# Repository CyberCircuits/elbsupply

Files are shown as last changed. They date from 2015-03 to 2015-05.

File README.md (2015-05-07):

## ElbSupply - A simple linear bench supply

ElbSupply is a linear bench power supply with an output voltage range of 0-20V and output current range of 0-3A.

Here are the OSHpark renderings of the boards:

For project details visit the [project page on Hackaday.io](https://hackaday.io/project/4407-elbsupply-simple-linear-bench-supply)

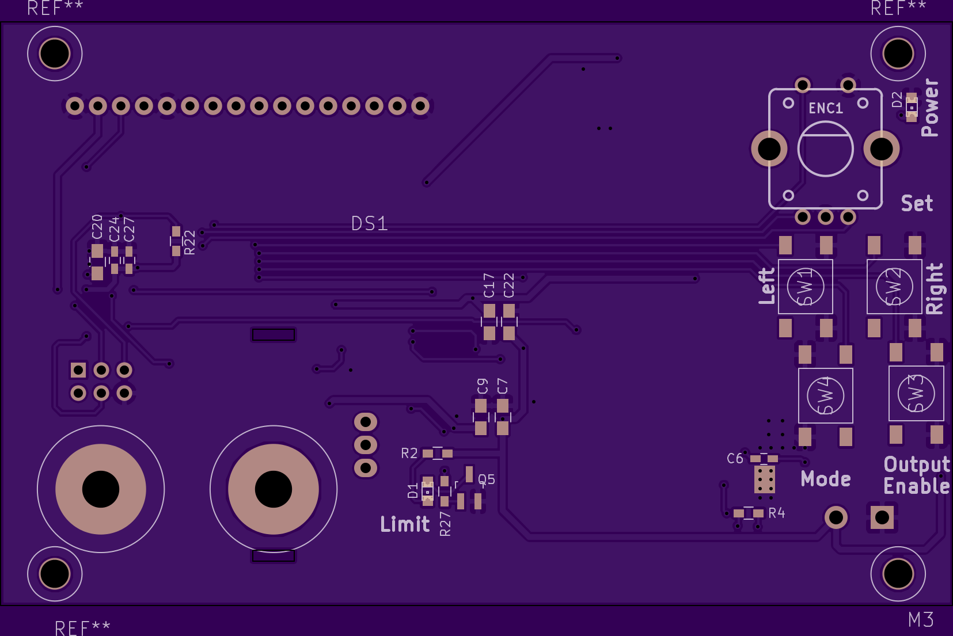
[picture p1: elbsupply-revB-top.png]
"Rev. B board top" Rev. B board top
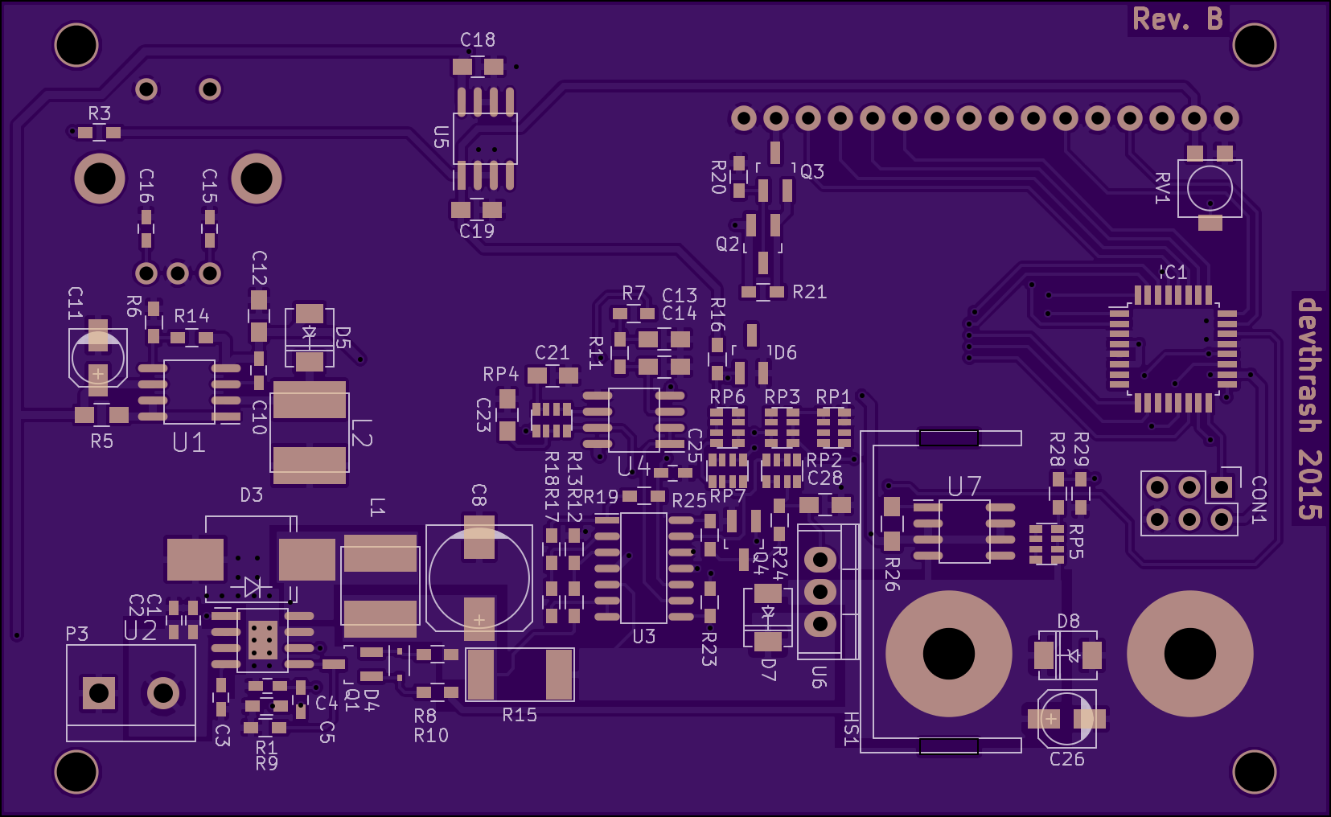
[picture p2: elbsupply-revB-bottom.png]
"Rev. B board bottom" Rev. B board bottom


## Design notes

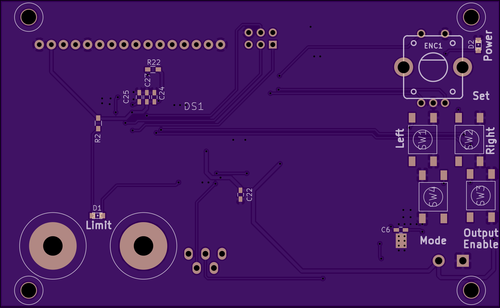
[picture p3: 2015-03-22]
elbsupply-revA-top.png

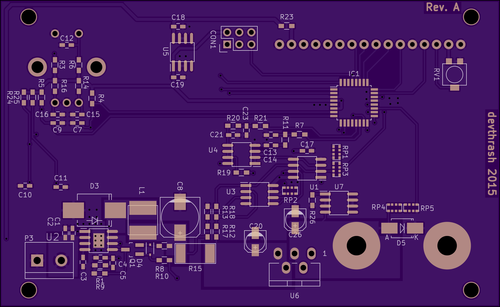
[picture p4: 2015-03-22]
elbsupply-revA-bottom.png

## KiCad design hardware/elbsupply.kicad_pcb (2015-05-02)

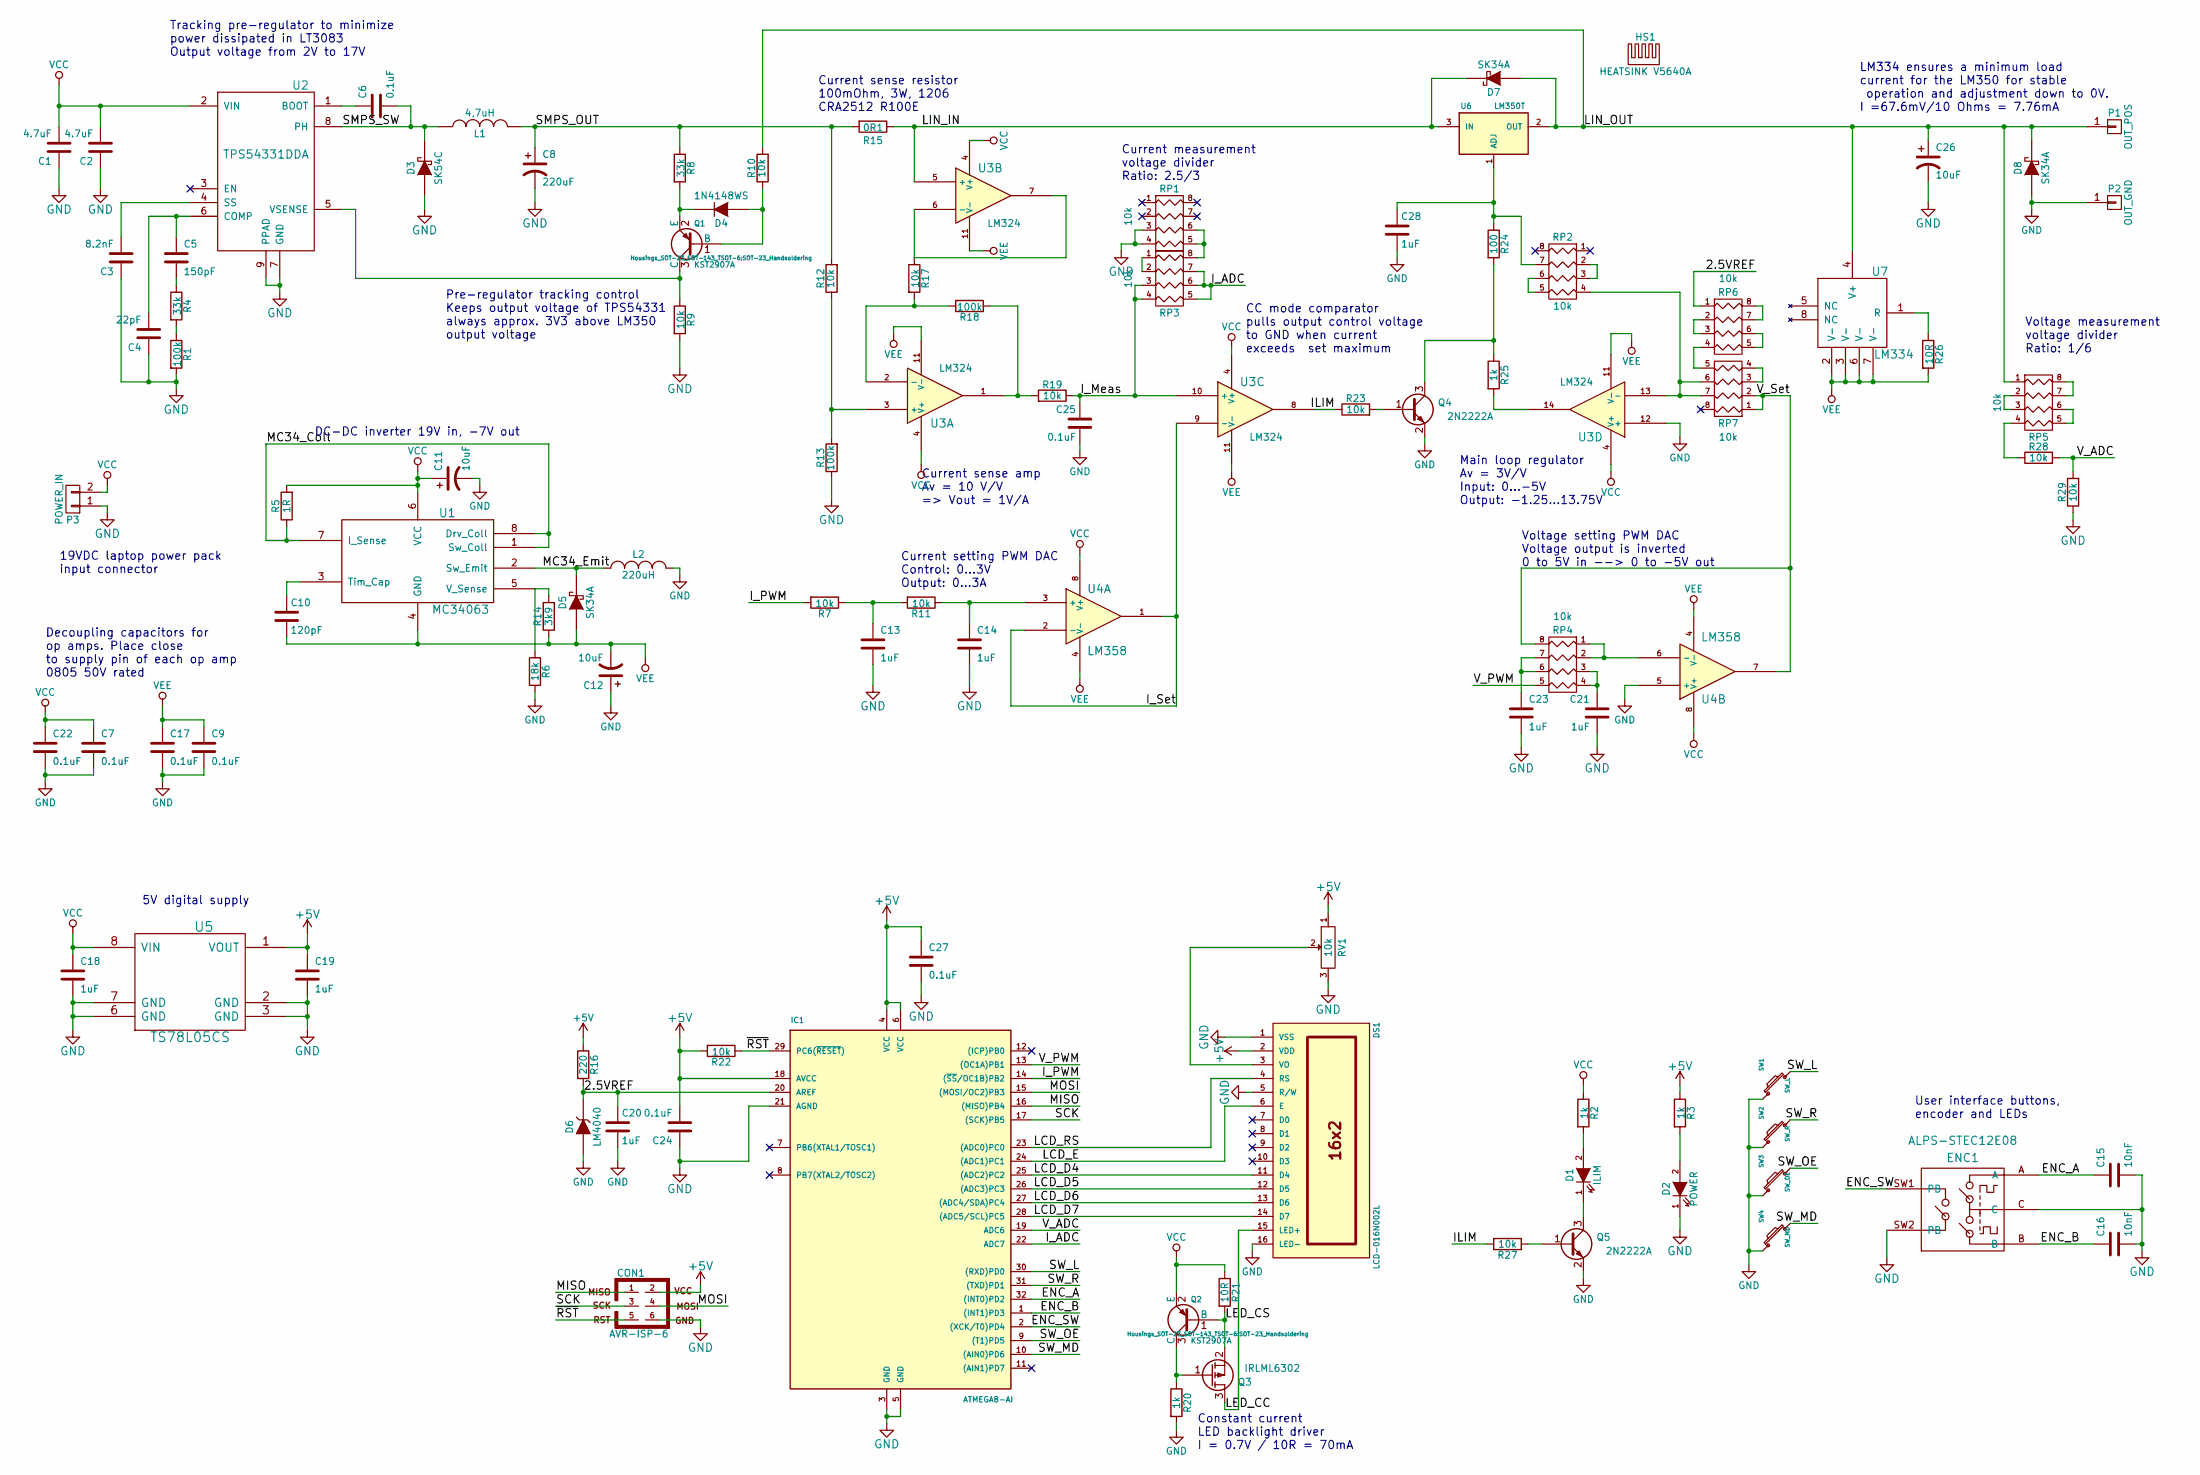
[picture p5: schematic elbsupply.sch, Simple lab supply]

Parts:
C1, C2: 4.7uF; C_0805_HandSoldering
C3: 8.2nF; C_0603_HandSoldering
C4: 22pF; C_0603_HandSoldering
C5: 150pF; C_0603_HandSoldering
C6, C7, C9, C17, C22, C24, C25, C27: 0.1uF; C_0805_HandSoldering
C8: 220uF; c_elec_8x10.5
C10: 120pF; C_0603_HandSoldering
C11, C26: 10uF; c_elec_4x4.5
C12: 10uF; C_0805_HandSoldering
C13, C14, C18, C19, C20, C21, C23, C28: 1uF; C_0805_HandSoldering
C15, C16: 10nF; C_0603_HandSoldering
CON1: AVR-ISP-6; Pin_Header_Straight_2x03
D1: ILIM; LED-0805
D2: POWER; LED-0805
D3: SK54C; Diode-SMC_Handsoldering
D4: 1N4148WS; SOD-323
D5, D7, D8: SK34A; DO-214-AC_SMA
D6: LM4040; SOT-23_Handsoldering
DS1: LCD-016N002L; LCD16X2
ENC1: ALPS-STEC12E08
HS1: HEATSINK V5640A; Heatsink-V5640A
IC1: ATMEGA8-AI; TQFP-32_7x7mm_Pitch0.8mm
L1: 4,7uH; 242418FPS-Fastron
L2: 220uH; 242418FPS-Fastron
P1: OUT_POS; SKS-PK10A
P2: OUT_GND; SKS-PK10A
P3: POWER_IN; bornier2
Q1, Q2: KST2907A; SOT-23_Handsoldering
Q3: IRLML6302; SOT-23_Handsoldering
Q4, Q5: 2N2222A; SOT-23_Handsoldering
R1, R13, R18: 100k; R_0603_HandSoldering
R2, R3, R20, R25: 1k; R_0603_HandSoldering
R4, R8: 33k; R_0603_HandSoldering
R5: 1R; R_0805_HandSoldering
R6: 18k; R_0603_HandSoldering
R7, R9, R10, R11, R12, R17, R19, R22, R23, R27, R28, R29: 10k; R_0603_HandSoldering
R14: 3k9; R_0603_HandSoldering
R15: 0R1; CRA2512-Bourns
R16: 220; R_0603_HandSoldering
R21: 10R; R_0603_HandSoldering
R24: 100; R_0603_HandSoldering
R26: 10R; R_0805_HandSoldering
RP1, RP2, RP3, RP4, RP5, RP6, RP7: 10k; YC164-Yageo-Handsoldering
RV1: 10k; BITech-23B
SW1: SW_L; Button-SMT-standard
SW2: SW_R; Button-SMT-standard
SW3: SW_OE; Button-SMT-standard
SW4: SW_MD; Button-SMT-standard
U1: MC34063; SO8
U2: TPS54331DDA; SO8-PowerPAD
U3: LM324; SO14
U4: LM358; SO8
U5: TS78L05CS; SO8
U6: LM350T; TO-220
U7: LM334; SO8

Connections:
+5V: C19.1, C24.2, C27.1, CON1.2, DS1.2 (VDD), IC1.4 (VCC), IC1.6 (VCC), IC1.18 (AVCC), R3.1, R16.1, R22.2, RV1.1, U5.1 (VOUT)
/2.5VREF: C20.1, D6.1 (K), IC1.20 (AREF), R16.2, RP6.1
/ENC_A: C15.1, ENC1.A, IC1.32 ((INT0)PD2)
/ENC_B: C16.1, ENC1.B, IC1.1 ((INT1)PD3)
/ENC_SW: ENC1.SW1 (PB), IC1.2 ((XCK/T0)PD4)
/ILIM: R23.1, R27.2, U3.8
/I_ADC: IC1.22 (ADC7), RP3.5 (R4), RP3.6 (R3), RP3.7 (R2)
/I_Meas: C25.1, R19.1, RP3.3, RP3.4, U3.10 (+)
/I_PWM: IC1.14 ((~SS~/OC1B)PB2), R7.2
/I_Set: U3.9 (-), U4.1, U4.2 (-)
/LCD_D4: DS1.11 (D4), IC1.25 ((ADC2)PC2)
/LCD_D5: DS1.12 (D5), IC1.26 ((ADC3)PC3)
/LCD_D6: DS1.13 (D6), IC1.27 ((ADC4/SDA)PC4)
/LCD_D7: DS1.14 (D7), IC1.28 ((ADC5/SCL)PC5)
/LCD_E: DS1.6 (E), IC1.24 ((ADC1)PC1)
/LCD_RS: DS1.4 (RS), IC1.23 ((ADC0)PC0)
/LED_CC: DS1.15 (LED+), Q3.3 (D)
/LED_CS: Q2.1 (B), Q3.2 (S), R21.2
/LIN_IN: D7.2 (K), R15.1, U3.5 (+), U6.3 (IN)
/LIN_OUT: C26.1, D7.1 (A), D8.2 (K), P1.1, R10.2, RP5.1, U6.2 (OUT), U7.4 (V+)
/MC34_Coll: R5.1, U1.1 (Sw_Coll), U1.7 (I_Sense), U1.8 (Drv_Coll)
/MC34_Emit: D5.2 (K), L2.1, U1.2 (Sw_Emit)
/MISO: CON1.1, IC1.16 ((MISO)PB4)
/MOSI: CON1.4, IC1.15 ((MOSI/OC2)PB3)
/SCK: CON1.3, IC1.17 ((SCK)PB5)
/SMPS_OUT: C8.1, L1.2, R8.1, R12.2, R15.2
/SMPS_SW: C6.2, D3.2 (K), L1.1, U2.8 (PH)
/SW_L: IC1.30 ((RXD)PD0), SW1.2
/SW_MD: IC1.10 ((AIN0)PD6), SW4.2
/SW_OE: IC1.9 ((T1)PD5), SW3.2
/SW_R: IC1.31 ((TXD)PD1), SW2.2
/V_ADC: IC1.19 (ADC6), R28.2, R29.2
/V_PWM: IC1.13 ((OC1A)PB1), RP4.5 (R4)
/V_Set: RP4.8 (R1), RP7.1, RP7.2, U4.7
/~RST~: CON1.5, IC1.29 (PC6(~RESET~)), R22.1
GND: C1.1, C2.1, C3.1, C4.1, C7.2, C8.2, C9.2, C11.2, C12.1, C13.2, C14.2, C15.2, C16.2, C17.2, C18.2, C19.2, C20.2, C21.2, C22.2, C23.2, C24.1, C25.2, C26.2, C27.2, C28.2, CON1.6, D2.1 (K), D3.1 (A), D6.2 (A), D8.1 (A), DS1.1 (VSS), DS1.5 (R/W), DS1.16 (LED-), ENC1.C, ENC1.SW2 (PB), IC1.3 (GND), IC1.5 (GND), IC1.21 (AGND), L2.2, P2.1, P3.1, Q4.2 (E), Q5.2 (E), R1.2, R6.2, R9.2, R13.1, R20.2, R29.1, RP1.3, RP1.4, RV1.3, SW1.1, SW2.1, SW3.1, SW4.1, U2.7 (GND), U2.9 (PPAD), U3.12 (+), U4.5 (+), U5.2 (GND), U5.3 (GND), U5.6 (GND), U5.7 (GND)
unnamed: C3.2, U2.4 (SS)
unnamed: C4.2, C5.1, U2.6 (COMP)
unnamed: C5.2, R4.1
unnamed: C6.1, U2.1 (BOOT)
unnamed: C10.1, U1.3 (Tim_Cap)
unnamed: C13.1, R7.1, R11.2
unnamed: C14.1, R11.1, U4.3 (+)
unnamed: C21.1, RP4.3, RP4.4
unnamed: C23.1, RP4.6 (R3), RP4.7 (R2)
unnamed: C28.1, R24.1, RP2.7 (R2), U6.1 (ADJ)
unnamed: D1.1 (K), Q5.3 (C)
unnamed: D1.2 (A), R2.2
unnamed: D2.2 (A), R3.2
unnamed: D4.1 (A), Q1.1 (B), R10.1
unnamed: D4.2 (K), Q1.2 (E), R8.2
unnamed: DS1.3 (VO), RV1.2
unnamed: Q1.3 (C), R9.1, U2.5 (VSENSE)
unnamed: Q2.3 (C), Q3.1 (G), R20.1
unnamed: Q4.1 (B), R23.2
unnamed: Q4.3 (C), R24.2, R25.1
unnamed: Q5.1 (B), R27.1
unnamed: R1.1, R4.2
unnamed: R12.1, R13.2, U3.3 (+)
unnamed: R6.1, R14.2, U1.5 (V_Sense)
unnamed: R17.1, U3.6 (-), U3.7
unnamed: R17.2, R18.2, U3.2 (-)
unnamed: R18.1, R19.2, U3.1
unnamed: R25.2, U3.14
unnamed: R26.1, U7.1 (R)
unnamed: R28.1, RP5.4
unnamed: RP1.5 (R4), RP1.6 (R3), RP3.8 (R1)
unnamed: RP2.2, RP2.3
unnamed: RP2.4, RP7.6 (R3), RP7.7 (R2), U3.13 (-)
unnamed: RP2.5 (R4), RP2.6 (R3)
unnamed: RP3.1, RP3.2
unnamed: RP4.1, RP4.2, U4.6 (-)
unnamed: RP5.2, RP5.3
unnamed: RP5.5 (R4), RP5.6 (R3)
unnamed: RP5.7 (R2), RP5.8 (R1)
unnamed: RP6.2, RP6.3
unnamed: RP6.4, RP7.5 (R4)
unnamed: RP6.5 (R4), RP6.6 (R3)
unnamed: RP6.7 (R2), RP6.8 (R1)
unnamed: RP7.3, RP7.4
VCC: C1.2, C2.2, C7.1, C11.1, C18.1, C22.1, P3.2, Q2.2 (E), R2.1, R5.2, R21.1, U1.6 (VCC), U2.2 (VIN), U3.4 (V+), U4.8 (V+), U5.8 (VIN)
VEE: C9.1, C10.2, C12.2, C17.1, D5.1 (A), R14.1, R26.2, U1.4 (GND), U3.11 (V-), U4.4 (V-), U7.2 (V-), U7.3 (V-), U7.6 (V-), U7.7 (V-)

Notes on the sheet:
Current sense amp Av = 10 V/V => Vout = 1V/A
Main loop regulator Av = 3V/V Input: 0...-5V Output: -1.25...13.75V
Current setting PWM DAC Control: 0...3V Output: 0...3A
Voltage setting PWM DAC Voltage output is inverted 0 to 5V in --> 0 to -5V out
Pre-regulator tracking control Keeps output voltage of TPS54331 always approx. 3V3 above LM350 output voltage
Tracking pre-regulator to minimize power dissipated in LT3083 Output voltage from 2V to 17V
CC mode comparator pulls output control voltage to GND when current exceeds set maximum
Current measurement voltage divider Ratio: 2.5/3
5V digital supply
Current sense resistor 100mOhm, 3W, 1206 CRA2512 R100E
Constant current LED backlight driver I = 0.7V / 10R = 70mA
Decoupling capacitors for op amps. Place close to supply pin of each op amp 0805 50V rated
19VDC laptop power pack input connector
DC-DC inverter 19V in, -7V out
User interface buttons, encoder and LEDs
LM334 ensures a minimum load current for the LM350 for stable operation and adjustment down to 0V. I =67.6mV/10 Ohms = 7.76mA
Voltage measurement voltage divider Ratio: 1/6

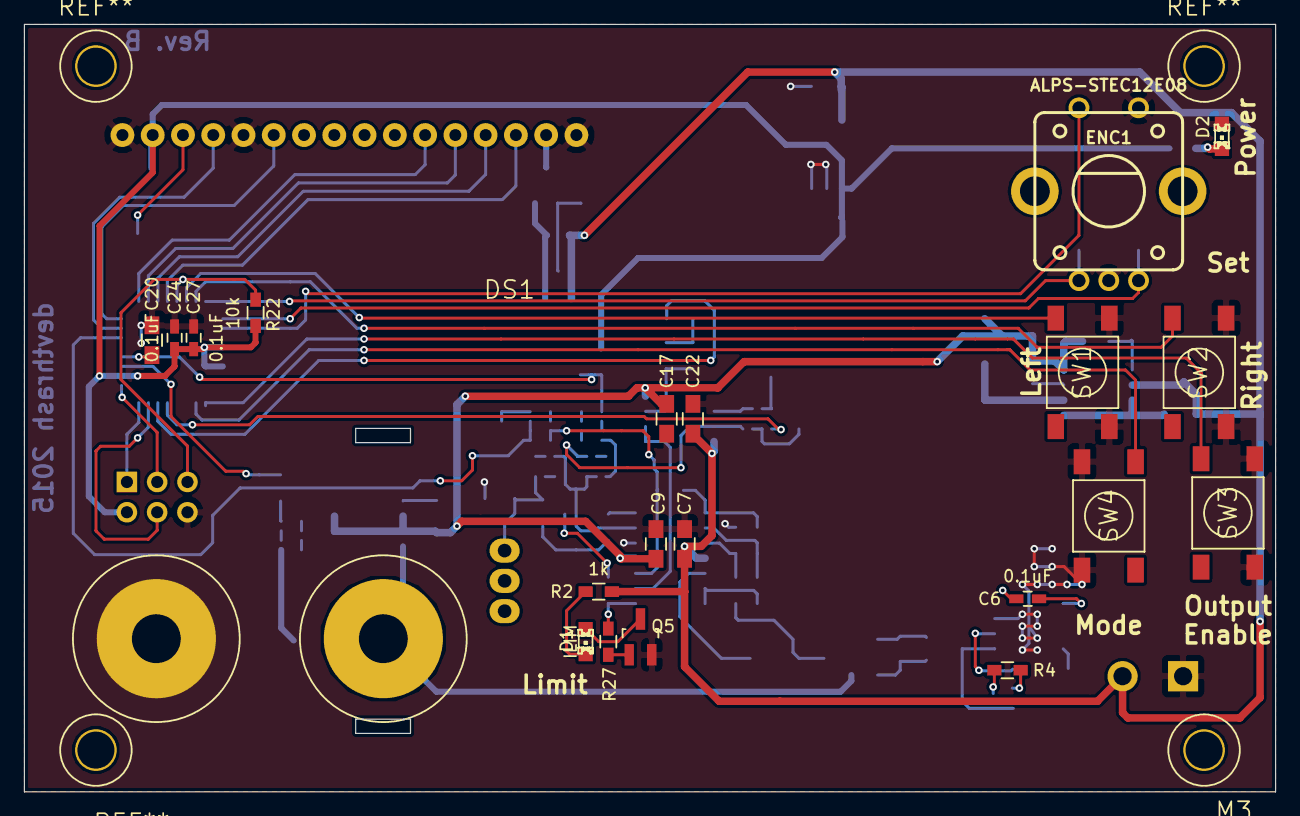
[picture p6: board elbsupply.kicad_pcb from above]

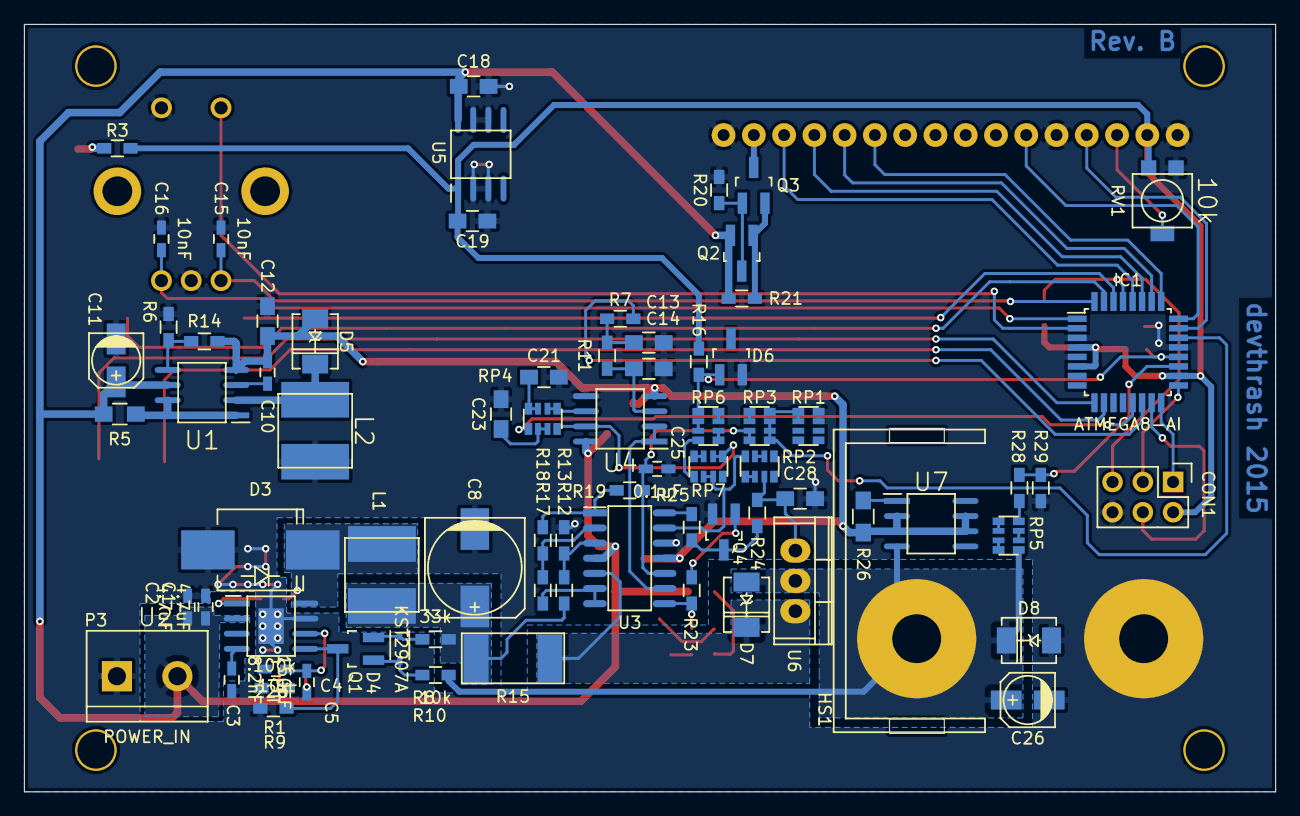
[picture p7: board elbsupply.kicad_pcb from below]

Board: 2 copper layers, 105.0 x 64.4 mm, 100 parts (76 on the bottom side), 82 nets.

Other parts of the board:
M3: Screw_PAN_Head_M3

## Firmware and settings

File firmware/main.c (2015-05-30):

#define F_CPU 8000000UL
#include <avr/io.h>
#include <avr/interrupt.h>
#include <util/delay.h>

#include "lcd.h"
#include "adc.h"
#include "pwm.h"

/* I/O mapping on the PCB
 * 
 * Inputs:
 * Button Left: 			PD0
 * Button right: 			PD1
 * Encoder button: 			PD2
 * Encoder A:				PD3
 * Encoder B:				PD4				
 * Button output enable: 	PD5
 * Button mode: 			PD6
 * 
 * output voltage:			ADC6
 * output current:			ADC7
 * 
 * Outputs:
 * Voltage set PWM:			PB1
 * Current set PWM:			PB2
 * LCD_RS:					PC0
 * LCD_E:					PC1
 * LCD_D4:					PC2
 * LCD_D5:					PC3
 * LCD_D6:					PC4
 * LCD_D7:					PC5
 */
#define BTN_LEFT	0x01
#define BTN_RIGHT	0x02
#define ENC_BTN		0x04
#define ENC_A		0x08
#define ENC_B		0x10
#define BTN_OE 		0x20
#define BTN_MODE	0x40

// define some flags for easier readability 
#define OUTMODE_CV 	0 
#define OUTMODE_CC 	1

// cursor shift directions
#define CURSHIFT_LEFT 0
#define CURSHIFT_RIGHT 1

// variables for LCD
char displayBuffer[2][16] = {
	"00.00V 0000mA CV",
	"00.00V 0000mA   "
};

uint8_t displayCurpos = 0;	// cursor position inside the display buffer
volatile uint16_t adcResampleTimeout = 0;

// voltage/current set points and actual measurements
// Adc = measured values
// Set = set values input by the user
// SetBuf = internal set buffer used for updating the PWM
uint16_t voltageSet, voltageSetBuf, voltageAdc = 0;
uint16_t currentSet, currentSetBuf, currentAdc = 0;

// PSU output mode and status
// 0 = output disabled, 1 = output enabled
uint8_t psuOutEnabled = 0;		
// 0 = constant voltage, 1 = constant current
uint8_t psuOutMode = 0;			

/* This approach to switch debouncing has been borrowed from Jack Ganssle
 * See http://www.ganssle.com/debouncing-pt2.htm for detailed description
 */
// number of timer interrupts after which a switch is considered debounced
#define SW_CHECKS 30
uint8_t swDebouncedState; 						// debounced state of the switches
volatile uint8_t swStateBuf[SW_CHECKS] = {0}; 	// holds SW_CHECKS consecutive switch state readings
volatile uint8_t swStateIndex = 0;				// array index for number of checks performed

/* Reads the raw state of the port input registers and fuses them
 * together into one byte to be used in the debouncing routine
 * 
 * The byte layout is as follows:
 * Bit	6		5		 4		  3		    2 		1 			0
 * BTN_MODE | BTN_OE | ENC_B | ENC_A | ENC_BTN | BTN_RIGHT | BTN_LEFT
 */
uint8_t getSwitchRaw(void)
{
	uint8_t tmp;
	tmp = (PIND & 0x7F) ^ 0xFF;	// invert read values because switches are active low
	return tmp;
}

/* Returns debounced state of the switches 
 * Return bit values: 1 if switch has changed, 0 otherwise 
 */
uint8_t getSwitchDebounced(void)
{
	uint8_t i,j,tmp;
	j = 0xFF;
	for (i = 0; i < SW_CHECKS; i++) j = j & swStateBuf[i];
	tmp = swDebouncedState ^ j;
	swDebouncedState = j;
	return tmp;
}

/* variables for encoder decoding
 * Encoder outputs are connected to external interrupt pins on 
 * the AVR which generate interrupts on any level change.
 *
 * In the ISR patterns are generated which are compared to the
 * reference patterns in order to determine which way the encoder
 * was spun
 */
uint8_t encRefLeft[5] = {0, 2, 3, 1, 0};
uint8_t encRefRight[5] = {0, 1, 3, 2, 0};
volatile uint8_t encTurnBuf[5];
volatile uint8_t encTurnIndex = 0;

int8_t getEncoderTurn(void)
{
	uint8_t i,j;
	// check wether the pattern matches with being turned right
	j = 5;
	for (i = 0; i < 5; i++)
	{
		if (encTurnBuf[i] == encRefRight[i]) j--;
	}
	
	if (j == 0) return 1;
	// check wether the pattern matches with being turend left
	j = 5;
	for (i = 0; i < 5; i++)
	{
		if (encTurnBuf[i] == encRefLeft[i]) j--;
	}
	
	if (j == 0) return -1;
	
	return 0;
}

/* shifts the cursor display position left or right depending on inc
 * if inc = 1: shift right
 * if inc = 0: shift left
 * this function ensures that the cursor is only moved to a position
 * of one of the digits of the set points on the LCD (cursor doesn't
 * move to digits that can't be modified)
 */
void lcdShiftCursor(uint8_t inc)
{
	switch (displayCurpos)
	{
	case 0:
		if (inc) displayCurpos++; 
		break;
		
	case 1:
		if (inc) displayCurpos += 2; 
		else displayCurpos--;
		break;
		
	case 3:
		if (inc) displayCurpos++;
		else displayCurpos -= 2;
		break;
		
	case 4: 
		if (inc) displayCurpos += 3;
		else displayCurpos--;
		break;
	
	case 7:
		if (inc) displayCurpos++;
		else displayCurpos -= 3;
		break;
	
	case 8:
		if (inc) displayCurpos++;
		else displayCurpos--;
		break;
				
	case 9:
		if (inc) displayCurpos++;
		else displayCurpos--;
		break;
						
	case 10:
		if (!inc) displayCurpos--;
		break;
	}
}

// define possible states of the finite state machine
typedef enum{
	STATE_IDLE,
	STATE_CRIGHT,
	STATE_CLEFT,
	STATE_ENCINC,
	STATE_ENCDEC,
	STATE_OE,
	STATE_MODE,
	STATE_PWMUPDATE,
	STATE_LCDUPDATE
}
SM_STATE;

// finite state machine registers
SM_STATE stateNext;

// each state of the FSM has it's own function
// return value is the next state of the FSM
SM_STATE stateIdle(void)
{
	uint8_t tmp;
	int8_t encState;
	
	tmp = getSwitchDebounced();
	encState = getEncoderTurn();
	
	if ( (swDebouncedState & BTN_OE) && (tmp & BTN_OE) ) {
		return STATE_OE;
	} else if ( (swDebouncedState & BTN_MODE) && (tmp & BTN_MODE)) {
		return STATE_MODE;
	} else if ( (swDebouncedState & BTN_LEFT) && (tmp & BTN_LEFT) ) {
		return STATE_CLEFT;
	} else if ( (swDebouncedState & BTN_RIGHT) && (tmp & BTN_RIGHT) ) {
		return STATE_CRIGHT;
	} else if ( encState == 1 ) {
		return STATE_ENCINC;
	} else if ( encState == -1 ) {
		return STATE_ENCDEC;
	} else if (adcResampleTimeout >= 244) {
		adcResampleTimeout = 0;
		return STATE_LCDUPDATE;
	} else {
		return STATE_IDLE;
	}
}

SM_STATE stateCRight(void)
{
	// shift the display cursor right by one
	lcdShiftCursor(CURSHIFT_RIGHT);
	LCD_setpos(displayCurpos);
	return STATE_IDLE;
}

SM_STATE stateCLeft(void)
{
	// shift the display cursor left by one
	lcdShiftCursor(CURSHIFT_LEFT);
	LCD_setpos(displayCurpos);
	return STATE_IDLE;
}

SM_STATE stateEncInc(void)
{
	// increase output voltage or current depending on cursor position
	switch (displayCurpos){
	case 0:
		if (voltageSet < 501) voltageSet += 1000;
		break;
					
	case 1:
		if (voltageSet < 1401) voltageSet += 100;
		break;
						
	case 3:
		if (voltageSet < 1491) voltageSet += 10;
		break;
						
	case 4:
		if (voltageSet < 1500) voltageSet += 1;
		break;
						
	case 7:
		if (currentSet < 2001) currentSet += 1000;
		break;
						
	case 8:
		if (currentSet < 2901) currentSet += 100;
		break;
						
	case 9:
		if (currentSet < 2991) currentSet += 10;
		break;
						
	case 10:
		if (currentSet < 2999) currentSet += 1;
		break;
	}
				
	// check wether the output is enabled
	if (psuOutEnabled == 1){
		// update internal set point buffers
		voltageSetBuf = voltageSet;
		currentSetBuf = currentSet;
		// update PWM
		return STATE_PWMUPDATE;
	} else {
		return STATE_LCDUPDATE;
	}
}

SM_STATE stateEncDec(void)
{
	// reduce output voltage or current depending on cursor position
	switch (displayCurpos){
	case 0: 
		if (voltageSet > 999) voltageSet -= 1000;
		break;
					
	case 1:
		if (voltageSet > 99) voltageSet -= 100;
		break;
						
	case 3:
		if (voltageSet > 9) voltageSet -= 10;
		break;
						
	case 4:
		if (voltageSet > 0) voltageSet -= 1;
		break;
						
	case 7:
		if (currentSet > 999) currentSet -= 1000;
		break;
						
	case 8:
		if (currentSet > 99) currentSet -= 100;
		break;
						
	case 9:
		if (currentSet > 9) currentSet -= 10;
		break;
					
	case 10:
		if (currentSet > 0) currentSet -= 1;
		break;
	}
	
	// check wether the output is enabled
	if (psuOutEnabled == 1){
		// update internal set point buffers
		voltageSetBuf = voltageSet;
		currentSetBuf = currentSet;
		// update PWM
		return STATE_PWMUPDATE;
	} else {
		return STATE_LCDUPDATE;
	}	
}

SM_STATE stateOE(void)
{
	// toggle output enable status bit
	psuOutEnabled ^= 1; 
					
	// enable output	
	if (psuOutEnabled == 1){
		// constant current mode
		if (psuOutMode == OUTMODE_CC){
			voltageSetBuf = 1500;
		} else { 						// constant voltage with current limiting mode
			voltageSetBuf = voltageSet;
		}
					
		currentSetBuf = currentSet;
	} else { 							// disable output
		voltageSetBuf = 0;
		currentSetBuf = 0;
	}
	
	return STATE_PWMUPDATE;
}

SM_STATE stateMode(void)
{
	// toggle internal output mode flag and disable output
	psuOutMode ^= 1;
	return STATE_OE;
}

SM_STATE statePWMUpdate(void)
{
	PWM_setPSUOutV(voltageSetBuf);
	PWM_setPSUOutI(currentSetBuf);
	return STATE_LCDUPDATE;
}

SM_STATE stateLCDUpdate(void)
{
	// measure actual output voltage and current
	voltageAdc = ADC_readPSUOutV();
	currentAdc = ADC_readPSUOutI();
	
	// format output voltage reading 
	displayBuffer[1][0] = (voltageAdc / 1000) + 48;
	displayBuffer[1][1] = ((voltageAdc % 1000) / 100) + 48;
	displayBuffer[1][3] = ((voltageAdc % 100) / 10) + 48;
	displayBuffer[1][4] = (voltageAdc % 10) + 48;
				
	// format output current reading
	displayBuffer[1][7] = (currentAdc / 1000) + 48;
	displayBuffer[1][8] = ((currentAdc % 1000) / 100) + 48;
	displayBuffer[1][9] = ((currentAdc % 100) / 10) + 48;
	displayBuffer[1][10] = (currentAdc % 10) + 48;
				
	// format output voltage setting
	displayBuffer[0][0] = (voltageSet / 1000) + 48;
	displayBuffer[0][1] = ((voltageSet % 1000) / 100) + 48;
	displayBuffer[0][3] = ((voltageSet % 100) / 10) + 48;
	displayBuffer[0][4] = (voltageSet % 10) + 48;
				
	// format output current setting
	displayBuffer[0][7] = (currentSet / 1000) + 48;
	displayBuffer[0][8] = ((currentSet % 1000) / 100) + 48;
	displayBuffer[0][9] = ((currentSet % 100) / 10) + 48;
	displayBuffer[0][10] = (currentSet % 10) + 48;
	
	// display "OE" marker if output is enabled
	if (psuOutEnabled == 1){
		displayBuffer[1][14] = 'O';
		displayBuffer[1][15] = 'E';
	} else {
		displayBuffer[1][14] = ' ';
		displayBuffer[1][15] = ' ';
	}
				
	// indicate wether PSU is in CC or CV mode
	if (psuOutMode == OUTMODE_CC)
	{
		displayBuffer[0][15] = 'C';
	} else {
		displayBuffer[0][15] = 'V';
	}
	
	cli();		
	// push updated displayBuffer to LCD
	LCD_set_cursor(0, 0);
	LCD_puts(displayBuffer[0]);
	LCD_set_cursor(1, 0);
	LCD_puts(displayBuffer[1]);
	LCD_setpos(displayCurpos);
	sei();
	
	return STATE_IDLE;
}

int main(void)
{
	// low level initialization
	LCD_init(0x28, 0x0E);	
	ADC_init();
	PWM_init();
	
	// input switches
	DDRB &= ~0xC0;
	DDRD &= ~0x7F;
		
	// enable pull up resistors
	PORTD |= 0x7F;

	voltageSet = 500;
	currentSet = 3000;
	
	// initialize FSM registers
	stateNext = STATE_LCDUPDATE;

	// configure external interrupts for encoder
	// any logical change in the INT0/1 pins causes interrupt
	MCUCR |= (1<<ISC10) | (1<<ISC00);
	GICR |= (1<<INT1) | (1<<INT0);

	// set up SysTick timer
	// Timer 0
	TIMSK |= (1<<TOIE0);	// enable overflow interrupt
	TCCR0 |= (1<<CS01) | (1<<CS00); // prescaler 64, interrupt freq: 8MHz/(256*64) = 488Hz
	sei();
	
	// simply execute the FSM
	while (1){
		
		switch (stateNext){
		case STATE_IDLE:
			stateNext = stateIdle();
			break;
				
		case STATE_CRIGHT:
			stateNext = stateCRight();
			break;
				
		case STATE_CLEFT:
			stateNext = stateCLeft();
			break;
				
		case STATE_ENCINC:
			stateNext = stateEncInc();
			break;
				
		case STATE_ENCDEC:
			stateNext = stateEncDec();
			break;
				
		case STATE_OE:
			stateNext = stateOE();
			break;
				
		case STATE_MODE:
			stateNext = stateMode();	
			break;
				
		case STATE_PWMUPDATE:
			stateNext = statePWMUpdate();
			break;
				
		case STATE_LCDUPDATE:
			stateNext = stateLCDUpdate();
			break;
		}
		
	}
}

ISR(TIMER0_OVF_vect)
{
	// acumulate SW_CHECKS number of samples of the switch states
	swStateBuf[swStateIndex] = getSwitchRaw();
	++swStateIndex;
	if (swStateIndex >= SW_CHECKS) swStateIndex = 0;
			
	// timeout counter for next ADC read/display update
	adcResampleTimeout++;
}

ISR(INT0_vect)
{
	if (PIND & 0x08)
	{
		encTurnBuf[encTurnIndex] = 2;
	} else {
		encTurnBuf[encTurnIndex] = 1;
	}
	++encTurnIndex;
	if (encTurnIndex > 4) encTurnIndex = 0;
}

ISR(INT1_vect){
	if (PIND & 0x04)
	{
		encTurnBuf[encTurnIndex] = 3;
	} else {
		encTurnBuf[encTurnIndex] = 0;
	}
	++encTurnIndex;
	if (encTurnIndex > 4) encTurnIndex = 0;
}

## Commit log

2015-02-24 changed pre-regulator to TPS54331DDA, need to calculate exact values
    [elbsupply.sch]
2015-02-27 final Rev. A schematic
    [elbsupply.sch]
2015-03-01 changed 5V regulator for surface mount version
    [elbsupply.sch]
2015-03-01 final Rev. A schematic annotated
    [elbsupply.sch]
2015-03-01 partially done with footprint association
    [elbsupply.sch]
2015-03-03 slight schematic changes, footprint association almost done
    [elbsupply.sch]
2015-03-04 component footprint association done
2015-03-04 added screw terminal power input
    [elbsupply.sch]
2015-03-04 started PCB layout, fixed some footprint association
    [elbsupply.kicad_pcb]
2015-03-04 binding post distance is now 3/4 inch
    [elbsupply.kicad_pcb, elbsupply.sch]
2015-03-05 fixed Q1 footprint issues
    [elbsupply.kicad_pcb, elbsupply.sch]
2015-03-05 continued layout
    [elbsupply.kicad_pcb, elbsupply.sch]
2015-03-07 parts placement largely finished
    [elbsupply.kicad_pcb]
2015-03-07 added PCB mounting holes, need repositioning of connectors and LCD
    [elbsupply.kicad_pcb]
2015-03-08 LT3083 output capacitors exchanged for electrolytics
    [elbsupply.kicad_pcb, elbsupply.sch]
2015-03-08 rev. A routing finished
    [elbsupply.kicad_pcb, elbsupply.sch]
2015-03-08 added two more switches for cleaner UI
    [elbsupply.kicad_pcb, elbsupply.sch]
2015-03-08 final reviision A routing done, need to add some logo
    [elbsupply.kicad_pcb]
2015-03-08 rev A board, ordered
    [elbsupply.kicad_pcb]
2015-03-08 quickly added LM334 constant current sink to ensure stable operation of LT3083
    [elbsupply.kicad_pcb, elbsupply.sch]
2015-03-09 made a mistake in LCD pinout, fixed in schematic, needs to be fixed on revision B board
    [elbsupply.sch]
2015-03-10 added ADC routines
2015-03-11 added PWM initialization
2015-03-12 PWM low level init and voltage to pulsewidth conversion code added
2015-03-13 fixed wrong LCD connection in Schematic
    [elbsupply.sch]
2015-03-13 split PWM functions into separate files
2015-03-15 added encoder voltage and current setting
2015-03-15 broke up FSM into function for each state with return value as next state of FSM
    [main.c]
2015-03-16 added switch debouncing
2015-03-16 added production outputs and BOM files to .gitignore
2015-03-16 improved debouncing further, now returns only 1 if switch status has changed
2015-03-16 fixed issues in Idle state, removed unnecessary stateCurret FSM register
    [main.c]
2015-03-19 fixed button read
2015-03-22 ignoring gerber files
2015-03-22 added board renderings
2015-04-11 mostly fixed LCD display routines and updating
    [main.c]
2015-04-13 changed components to improve loop stability
    [elbsupply.sch]
2015-04-18 improved current limiting circuit, constant current LCD LED backlight driver
    [elbsupply.sch]
2015-04-18 changed voltage measurement divider to new voltage range
    [elbsupply.sch]
2015-04-18 changed max output voltage
2015-04-19 exchanged LT3083 for LM350, added negative rail and offset amplifiers
    [elbsupply.sch]
2015-04-19 extended negative rail to -7V, improved voltage adjustment
    [elbsupply.sch]
2015-04-21 adjusted minimum load current, added heatsink
    [elbsupply.sch]
2015-04-21 code cleanup, added comments to explain encoder decoding
2015-04-23 main control voltage op amp has voltage shifted down by 1.25V for LM350 0V output
    [elbsupply.sch]
2015-04-23 changed tracking preregulator output tracking and compensation
    [elbsupply.sch]
2015-04-23 finalized Rev. B schematic, started new component association
    [elbsupply.sch]
2015-04-24 Rev B component association done
    [elbsupply.sch]
2015-04-25 started new layout
    [elbsupply.kicad_pcb, elbsupply.sch]
2015-04-27 continued board layout
    [elbsupply.kicad_pcb, elbsupply.sch]
2015-05-02 RevB layout finished
    [elbsupply.kicad_pcb, elbsupply.sch]
2015-05-02 rev B. ordered, exchnaged heatsink slots for PCB cutouts
    [elbsupply.kicad_pcb]
2015-05-07 added Rev. B board renderings
2015-05-30 enabled pull-up resistors on needed pins
2015-05-30 corrected button association for Rev. B PCB
    [main.c]
2015-05-30 corrected voltage measurement and voltage set routines for Rev. B board
    [main.c]
2015-05-30 fixed voltage set buffer amp gain
    [elbsupply.sch]
2015-05-30 fixed current mode pull down transistor, current limiting works as expected
    [elbsupply.sch]
